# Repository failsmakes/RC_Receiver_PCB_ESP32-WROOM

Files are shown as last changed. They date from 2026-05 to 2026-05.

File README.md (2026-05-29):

# MakerZ RC Receiver PCB for ESP32-WROOM

Bu proje, [RC-Receiver-ESP](https://github.com/failsmakes/RC-Receiver-ESP) yazılımı için tasarlanmış **ESP32-WROOM tabanlı RC alıcı devresinin PCB çizimini** içerir. Tasarım **KiCad 10.0.1** ile hazırlanmıştır.

## 📌 Proje Özeti
Bu kart, RC sinyallerini ESP32 üzerinden işleyebilmek için optimize edilmiştir. Üzerinde güç regülasyonu, servo ve motor çıkışları, MPU6050 sensör bağlantısı ve MP1584 voltaj modülü için yerleşim alanları bulunur.

## 🧩 Teknik Bileşenler
- **ESP32-WROOM-32 DevKit V1**  
- **MP1584 DC-DC Regülatör Modülü**  
- **MPU6050 IMU Sensör Modülü**  
- **Servo ve Motor çıkış pinleri**  
- **Güç girişleri:** +BATT, +5V, GND  
- **Bağlantı pinleri:** SDA, SCL, INT, VCC  

## 📂 Dosya İçeriği
- `RC_Receiver_PCB_ESP32-WROOM.kicad_pcb` → PCB çizimi  
- `RC_Receiver_PCB_ESP32-WROOM.sch` → Şematik dosyası  
- `MakerZ RC Receiver ESP32 WROOM Schematic.pdf` → Şema PDF çıktısı  
- `gerber/` → Üretim dosyaları  
- `README.md` → Bu açıklama dosyası  

## 🖼️ PCB Görselleri
### Üst Katman
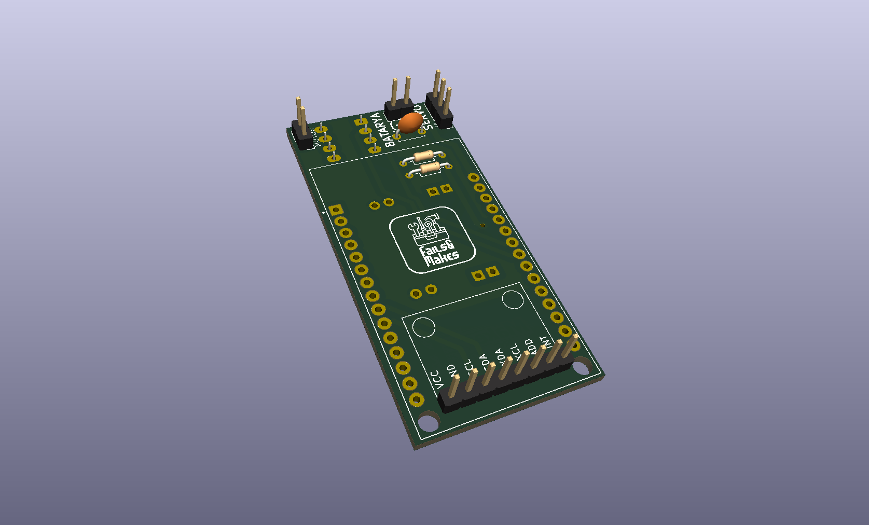
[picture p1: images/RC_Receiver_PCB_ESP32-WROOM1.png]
PCB Top View


### Alt Katman
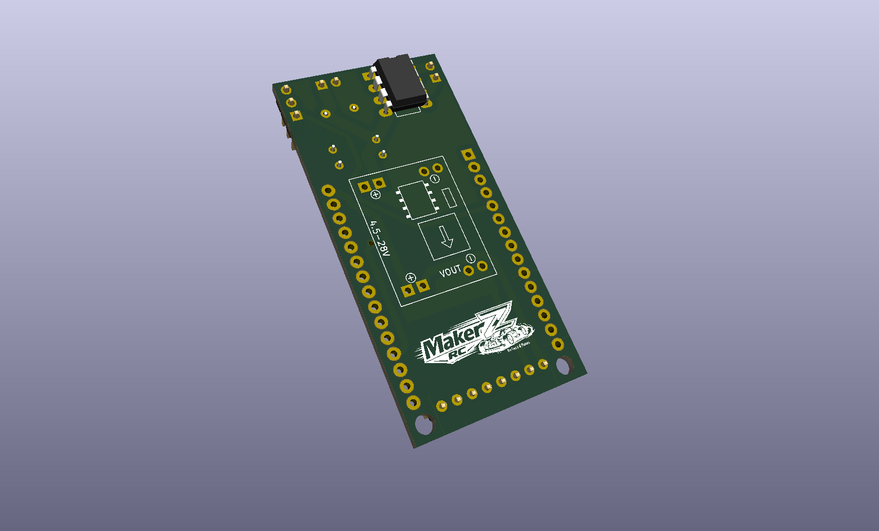
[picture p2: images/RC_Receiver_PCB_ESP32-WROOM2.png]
PCB Bottom View


## 🚀 Kullanım
1. KiCad ile açarak şematik ve PCB tasarımını inceleyin.  
2. `gerber/` klasöründeki dosyaları kullanarak PCB üretimi yaptırabilirsiniz.  
3. ESP32-WROOM modülünü ve gerekli komponentleri lehimleyerek RC-Receiver-ESP yazılımını yükleyin.  

## 🔗 İlgili Proje
Bu PCB tasarımı, [RC-Receiver-ESP](https://github.com/failsmakes/RC-Receiver-ESP) yazılım projesi ile birlikte kullanılmak üzere hazırlanmıştır.

## 📜 Lisans
Bu proje açık kaynaklıdır. Detaylar için lisans dosyasına göz atın.

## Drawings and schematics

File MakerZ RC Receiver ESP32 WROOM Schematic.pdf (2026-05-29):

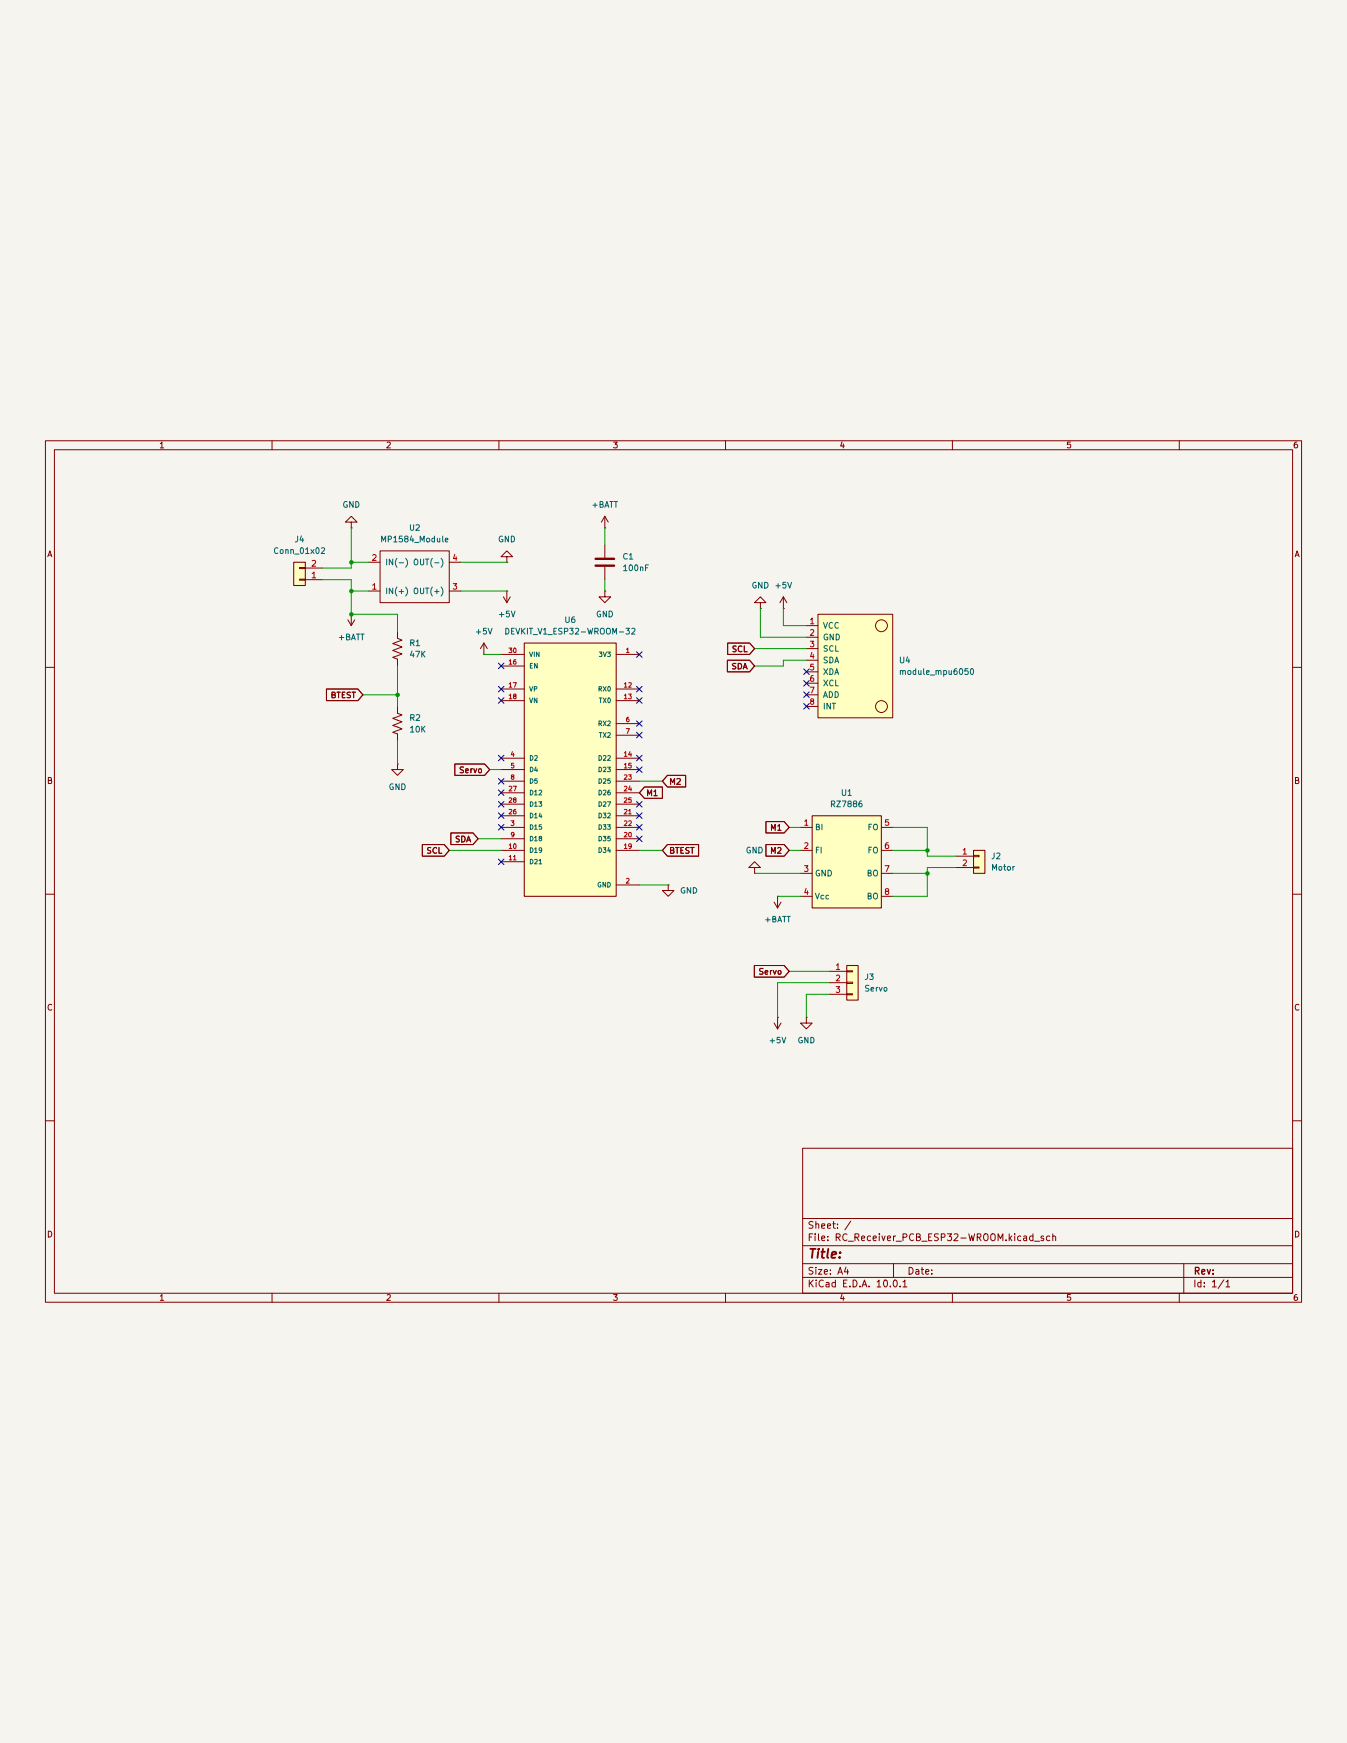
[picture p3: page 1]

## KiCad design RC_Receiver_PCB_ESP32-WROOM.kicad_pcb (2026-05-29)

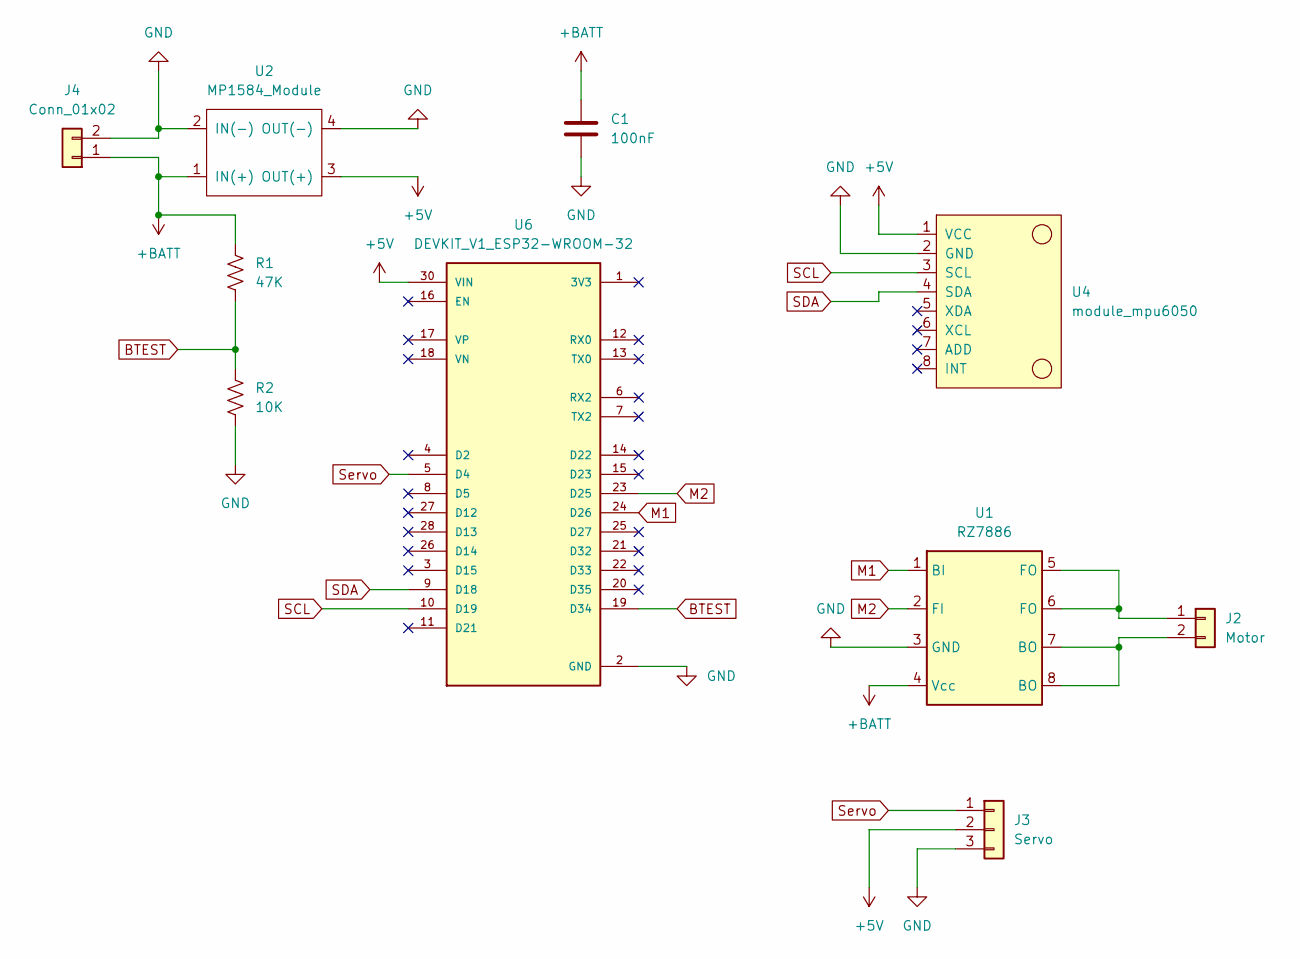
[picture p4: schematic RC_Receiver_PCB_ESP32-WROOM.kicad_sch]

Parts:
C1: 100nF; C_Disc_D5.0mm_W2.5mm_P5.00mm
J2: Motor; PinHeader_1x02_P2.54mm_Vertical
J3: Servo; PinHeader_1x03_P2.54mm_Vertical
J4: Conn_01x02; PinHeader_1x02_P2.54mm_Vertical
R1: 47K; R_Axial_DIN0204_L3.6mm_D1.6mm_P7.62mm_Horizontal
R2: 10K; R_Axial_DIN0204_L3.6mm_D1.6mm_P7.62mm_Horizontal
U1: RZ7886; DIP-8_W7.62mm_LongPads
U2: MP1584_Module; SRT_MPT1584EN_Module
U4: module_mpu6050
U6: DEVKIT_V1_ESP32-WROOM-32; MODULE_DEVKIT_V1_ESP32-WROOM-32

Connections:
+5V: J3.2, U2.3 (OUT(+)), U4.1 (VCC), U6.30 (VIN)
+BATT: C1.1, J4.1, R1.1, U1.4 (Vcc), U2.1 (IN(+))
BTEST: R1.2, R2.1, U6.19 (D34)
GND: C1.2, J3.3, J4.2, R2.2, U1.3 (GND), U2.2 (IN(-)), U2.4 (OUT(-)), U4.2 (GND), U6.2 (GND), U6.29 (GND)
M1: U1.1 (BI), U6.24 (D26)
M2: U1.2 (FI), U6.23 (D25)
unnamed: J2.1, U1.5 (FO), U1.6 (FO)
unnamed: J2.2, U1.7 (BO), U1.8 (BO)
SCL: U4.3 (SCL), U6.10 (D19)
SDA: U4.4 (SDA), U6.9 (D18)
Servo: J3.1, U6.5 (D4)

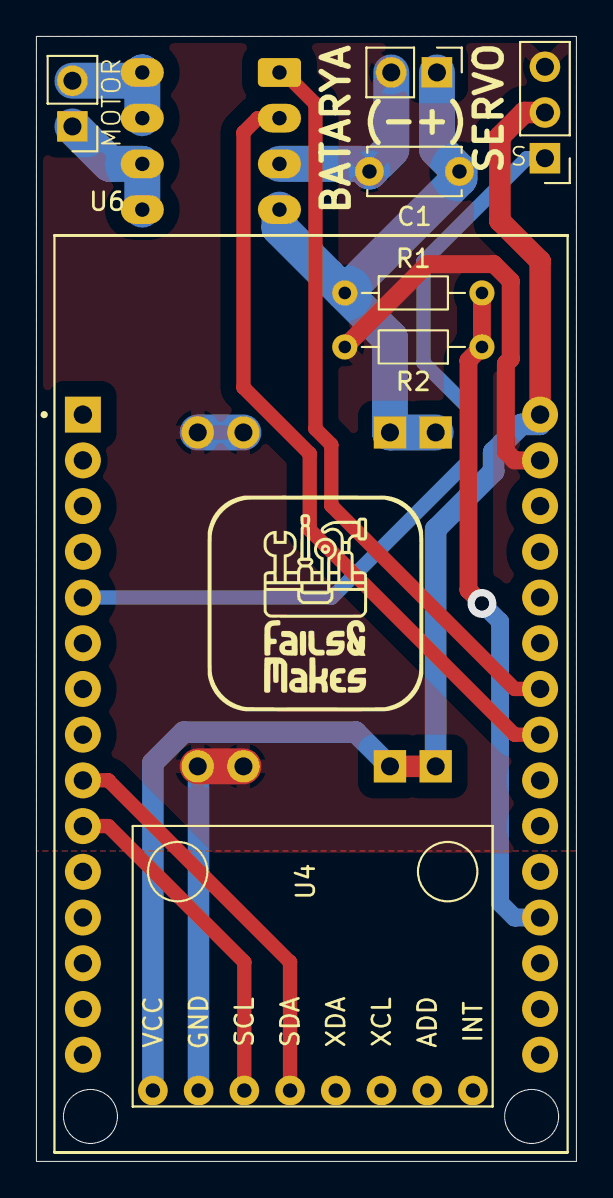
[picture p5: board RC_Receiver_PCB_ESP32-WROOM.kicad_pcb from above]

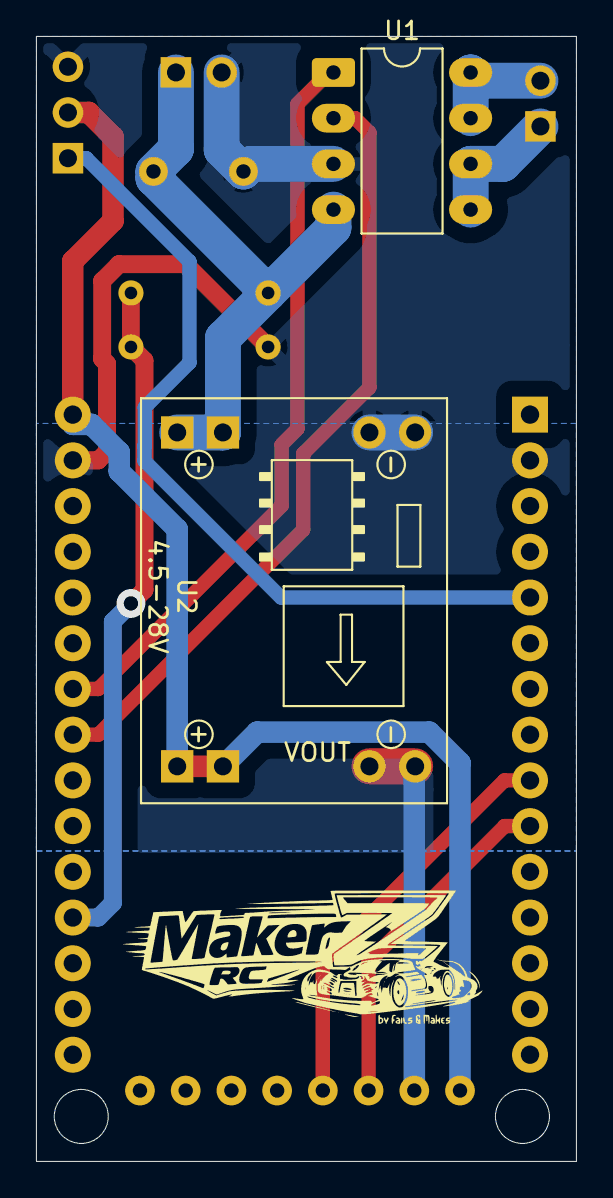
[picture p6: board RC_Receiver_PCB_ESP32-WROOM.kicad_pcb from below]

Board: 2 copper layers, 30.0 x 62.5 mm, 10 parts (2 on the bottom side), 11 nets.

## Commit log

2026-05-29 Revise README for RC Receiver PCB project
    Updated README to include project details and usage instructions.
2026-05-29 Replace PCB images with updated versions
    Updated PCB images in README with new filenames.
